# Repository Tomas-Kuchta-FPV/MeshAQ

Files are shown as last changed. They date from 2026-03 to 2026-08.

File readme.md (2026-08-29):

# MeshAQ
A portable sensor node designed to be carried and deployed anywhere.

This project serves as a development platform for Meshtastic, aiming to integrate the SEN6x family of environmental sensors and to support future upgrades in air quality and environmental telemetry within the Meshtastic ecosystem.

This project aimed to create the ultimate Air Quality sensor station to monitor. But after being a bit bussy I didn't have time to make it up to my original idea.  
But I managed to make a super small neat little all in one AQ helth monitor. Although I miss the other sensors.  
Formaldehyde sensor is super expensive and an increased levels can can be deducted from the VOC index.  

So yeah I'm so happy with the result! A neat little usb powered AQ station.

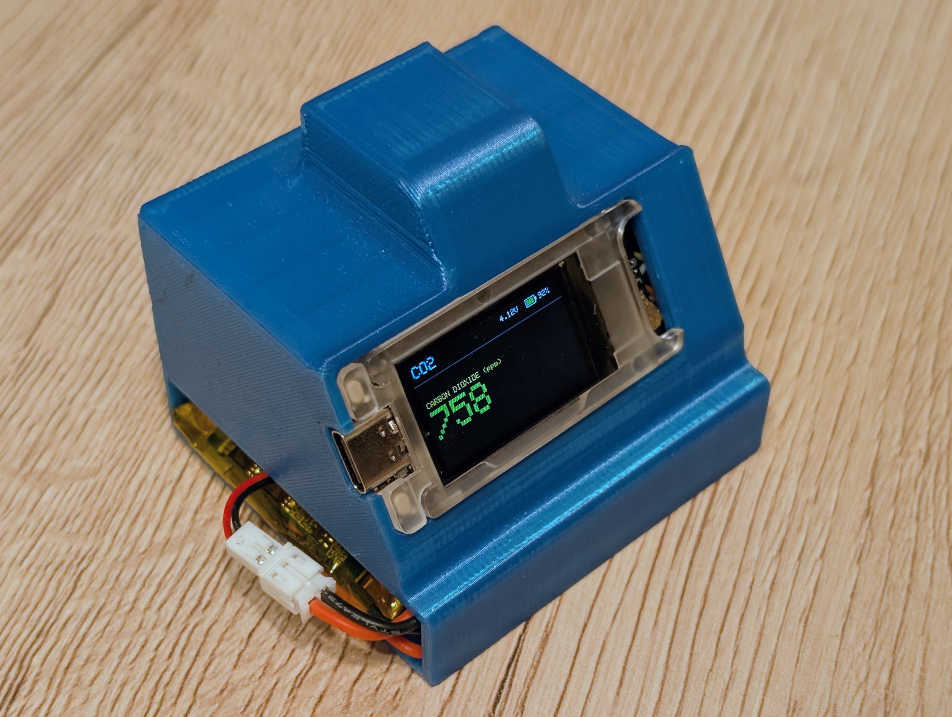
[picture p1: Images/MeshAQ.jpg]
Finished product


## Wiring diagram

| Heltec T114 Pin | SEN66 Pin | LaskaKit cable color |
| --- | --- | --- |
| GND | GND | Black |
| 3V3 | VCC | Red |
| GPIO 0.16 (SDA) | SDA | Blue |
| GPIO 0.13 (SCL) | SCL | Yellow |

## Sensors

| Measurement | Unit  | Sensor | Significance | Unhealthy level - suden spikes | Unhealthy level - 24h average |
| --- | ----- | --- | --- | --- | --- |
| Temperature | °C | SEN66  | Affects human comfort and thermoregulation; influences pollutant chemistry. | | >30°C (heat stress risk) |
| Relative humidity | % | SEN66  | Impacts respiratory comfort, aerosol growth, and mould/virus survival. | | <30% (dry) or >60% (mould/comfort issues) |
| PM (PM2.5) | µg/m³ | SEN66  | Fine particles penetrate lungs/bloodstream; linked to cardio-respiratory disease. | | annual ≤5 µg/m³; 24‑h >15 µg/m³ (exceedance) |
| PM (PM10) | µg/m³ | SEN66  | Alergens, dust and visible particles | |
| VOC Index | - | SEN66  | Sensor reports a relative VOC Index (unitless); indicates overall VOC load. | | Index >100 |
| NOx (NO2) | - | SEN66  | Sensor reports a relative NOx Index (unitless); NO2 is a respiratory irritant. | | Index >100 |
| CO2 | ppm | SEN66  | Proxy for ventilation and occupancy; high levels impair cognition. | | >1000 ppm (poor ventilation) |

### Future upgrades

| Measurement  | Unit  | Sensor | Significance | Unhealthy level - 24h average |
| --- | ----- | --- | --- | --- |
| Formaldehyde | ppm | SFA40 | Irritant and known carcinogen; common indoor emission from materials. | ?? |
| Ground Ozone | µg/m³ | (TBD) | Respiratory irritant and strong oxidant; forms from NOx/VOCs and sunlight. | Peak-season 8‑hr mean >60 µg/m³ |
| UV Index | - | LTR390UV / AMS AS7331 | Indicates UV radiation intensity; affects skin/eye health and photochemistry. | UVI >8 (very high/extreme exposure) |
| Sound level  | dB | TDK ICS43432 (mic) | High noise impacts sleep, stress, and hearing; affects wellbeing indirectly.  | >85 dB (prolonged exposure harmful) |

### Resources

- AI - It was crosschecked with material bellow
- https://www.who.int/publications/i/item/9789240034228
- https://sensirion.com/media/documents/02232963/6294E043/Info_Note_VOC_Index.pdf
- https://sensirion.com/media/documents/9F289B95/6294DFFC/Info_Note_NOx_Index.pdf
- https://sensirion.com/products/catalog/SEN66

## Renders

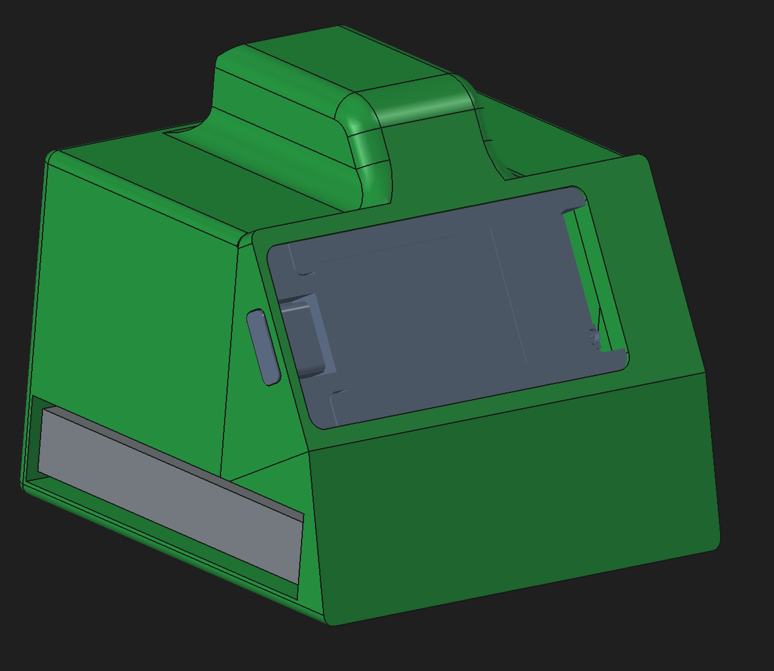
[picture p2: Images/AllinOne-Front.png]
Front
  
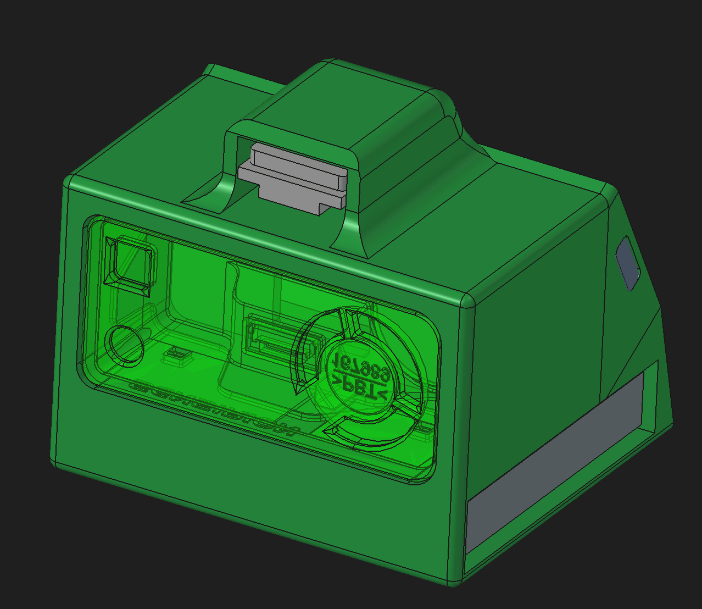
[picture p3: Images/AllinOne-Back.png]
Back
  
### Prototype
Prototype  

## Software

### Prototype for outpost
It will have it's own custom Arduino code made to interface with the sensor and display the values on the Eink screen.  

### Final version
I'm hoping to integrate it into meshtastic.  

## BOM

| Item | Price (USD) | Link & source |
| --- | --- | --- |
| 3d printed case | ~ 1 | MeshAQ.3mf |
| Heltec Mesh Node T114 | 63.38 | https://www.laskakit.cz/heltec-mesh-node-t114-v2-0-868mhz-nrf52840-sx1262/?variantId=17030 |
| SEN66 AQ sensor | 68.96 | https://www.laskakit.cz/senserion-sen66-sin-t-senzor-kvality-ovzdusi/ |
| JST GHR-06V-S connector | 0.85 | https://www.laskakit.cz/laskakit-airboard-propojovaci-kabel-pro-senserion-sen6x-senzor-kvality-ovzdusi/ |
| battery | 10.31 | https://www.laskakit.cz/baterie-li-po-3-7v-3000mah-lipo/ |
| JST-PH-2 2mm to JST 1.25mm | 0.85 | https://www.laskakit.cz/jst-ph-2-2mm-do-jst-gh-2-1-25mm-adapter-pro-baterie/ |
| Total | 144,35 |

## HackClub is fire! 🔥
https://blueprint.hackclub.com/projects/11552
https://github.com/Tomas-Kuchta-FPV/MeshAQ

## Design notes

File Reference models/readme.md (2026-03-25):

# Resources

SEN6x https://sensirion.com/products/catalog/SEN66  
heltec T114  
    https://www.printables.com/model/1610897-heltec-t114-simplified-3d-model/  
    https://www.printables.com/model/1003110-heltec-t114v1-model-file  
GPS L7GK
    https://www.printables.com/model/1604503-l76k-gnss-gps-board
case
    https://www.printables.com/model/797822-bender-battery-case-for-the-heltec-v3-heltec-t114

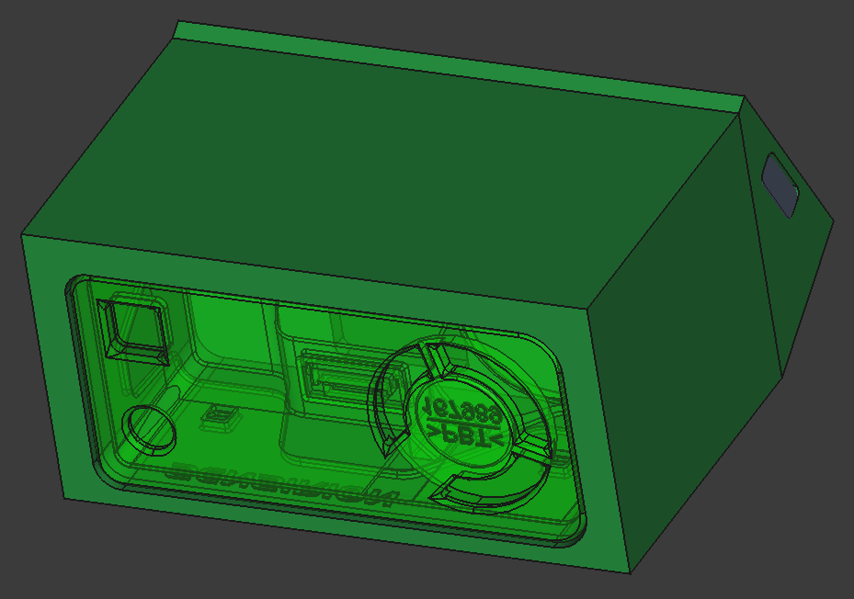
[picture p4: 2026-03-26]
Images/Back.png

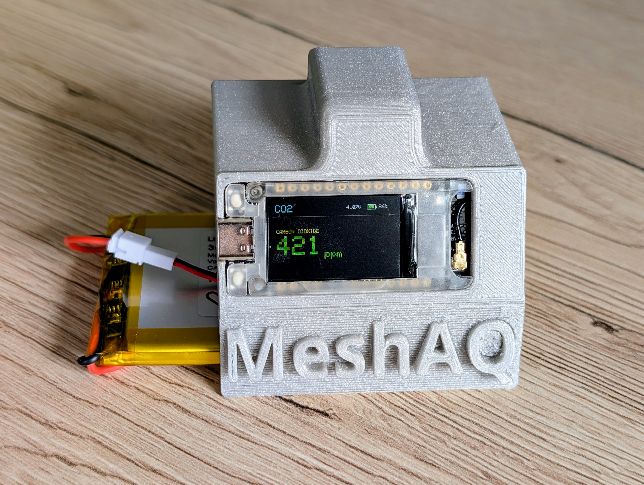
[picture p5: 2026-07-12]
Images/Finished product.jpg

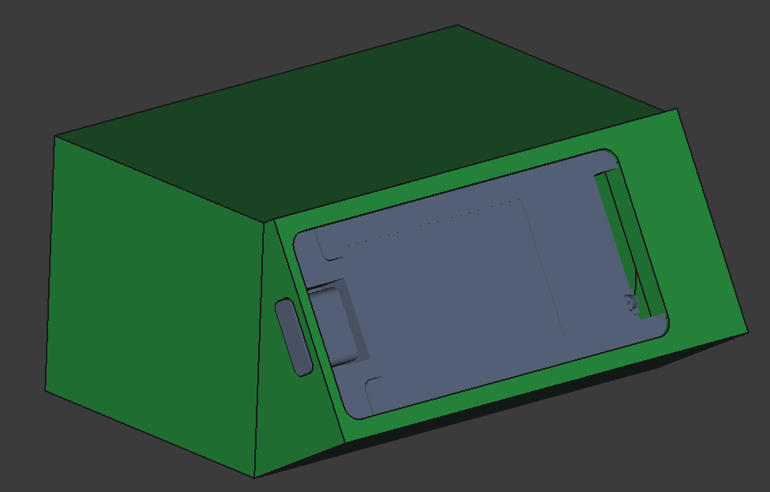
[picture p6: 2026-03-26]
Images/Front.png

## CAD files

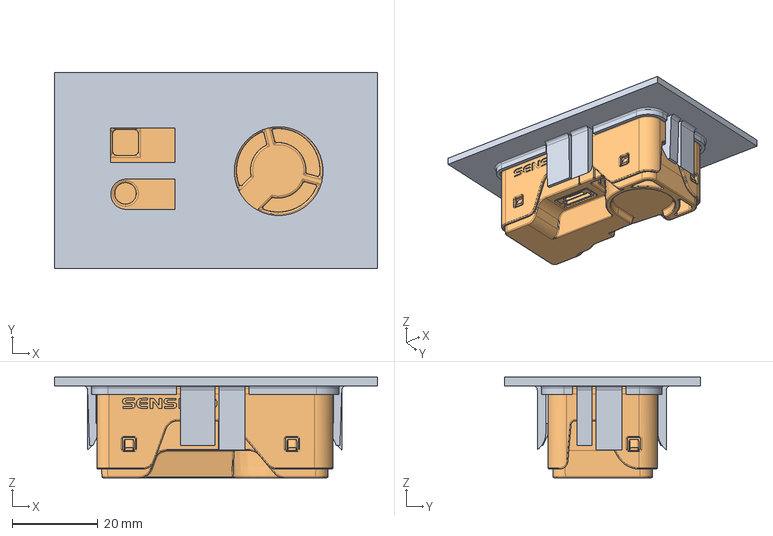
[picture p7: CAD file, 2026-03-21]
Reference models/SEN6x assembly.FCStd
75.5 x 45.9 x 23.5 mm
retainer_005
175875-00_Publication 3D File SEN6x

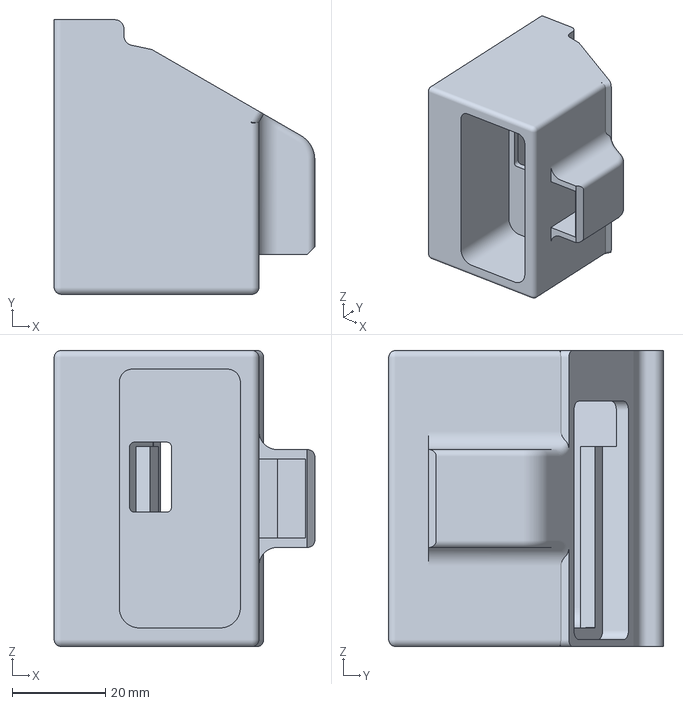
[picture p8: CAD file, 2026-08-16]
MeshAQ-3DPrintFile.3mf
56.0 x 59.0 x 63.6 mm

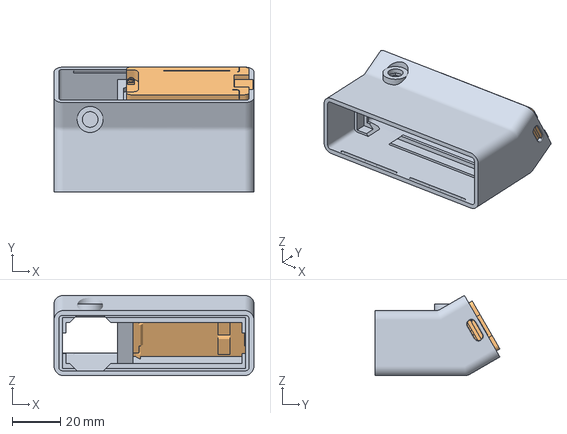
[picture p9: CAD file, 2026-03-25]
Reference models/bender.FCStd
83.0 x 51.8 x 33.3 mm
BenderBodyTopAntV1
HeltecT114 - Simplified dimensional drawing

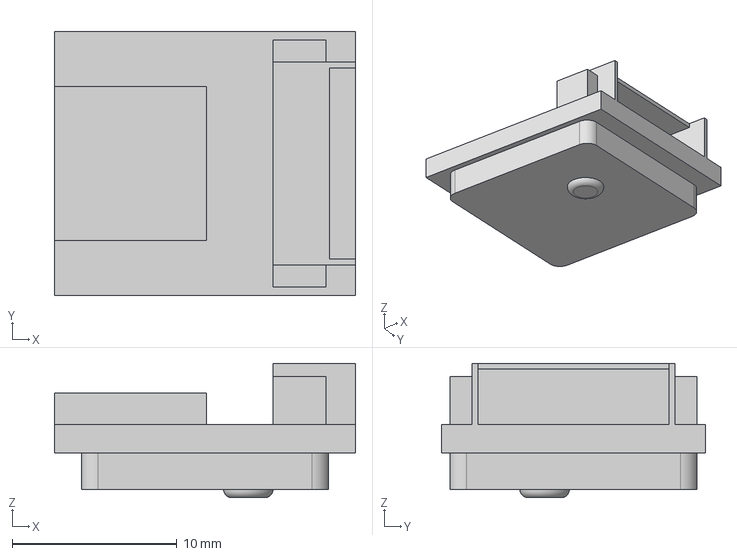
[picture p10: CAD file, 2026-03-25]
Reference models/l76k-gps-module.step
18.2 x 16.0 x 8.15 mm

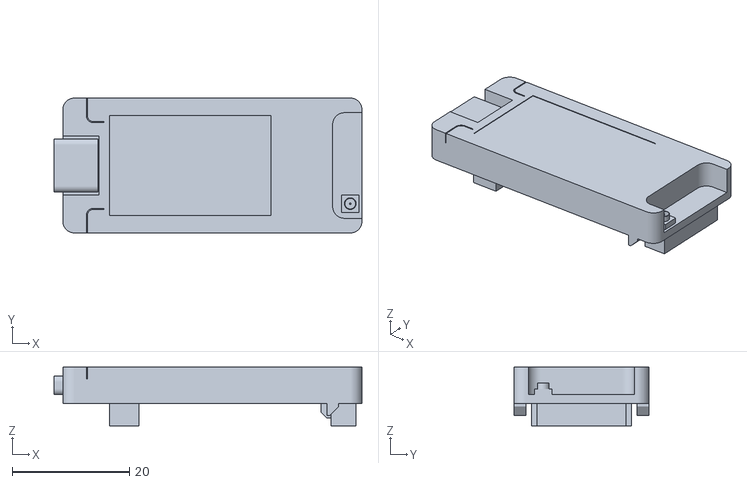
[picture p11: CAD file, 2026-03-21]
Reference models/HeltecT114 - Simplified dimensional drawing.stl
52.5 x 23.0 x 10.00

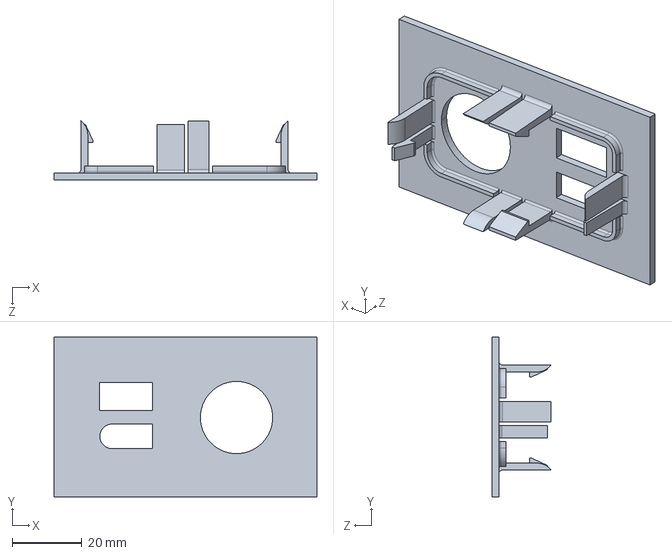
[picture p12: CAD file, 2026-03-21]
Reference models/SEN6x_Example_Retainer.step
75.5 x 45.9 x 17.0 mm

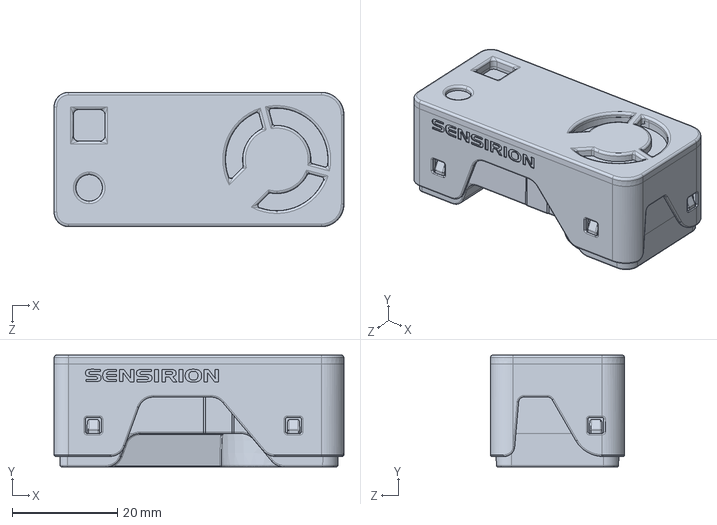
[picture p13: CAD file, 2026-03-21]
Reference models/PS_CD_SEN6x_D1.step
55.2 x 21.3 x 25.6 mm

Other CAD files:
MeshAQ-CAD.FCStd

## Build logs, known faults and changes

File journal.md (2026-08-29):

<!--
  Part of this journal is auto generated by Hack Club Blueprint.
-->

**Total Hours: 43.2h**
**Total Build Hours: 20.2h**

# 2/7/2026 1 PM - Research on enviromental monitoring  

_Time spent: 4.0h_  

I did a lot of research on enviromental monitoring.

I would like to measure metrics with which anyone can come into contact in everyday life.
I think that **temperature** and **relative humidity** are a baseline for comfort.
For office/home use I like **CO2**, **PM2.5**. These are all the basic ones which should suite almost everyone.

**Ground level ozone** seems like a great thing for an everyday node. 
**NO₂** and **Formaldehyde** are not super nessesary for everyday life but it's good to note traffic pollution and carcidogens. **VOCs** are good to measure but not strictly nesecery.
Then I started thinking about the **UV index** and **sound polution**, because smart citizen kits also measure these kinds of data. and it makes sense.

But I'm not a normal human.
I use paints, solvents, solder and other random stuff. So I also need **VOCs** and the other stuff. Also I would like to know how to mitigate the sources.

My references and sources are:
https://www.hackster.io/21cncstudio/project-aura-open-source-esp32-air-quality-monitor-8cb256
https://sensirion.com/products/catalog/particulate-matter-sensors
https://sensirion.com/products/catalog/SEN66
	There is already an arduino library for it.
	https://github.com/paulvha/SEN6X
	https://github.com/Sensirion/arduino-i2c-sen66
https://meshtastic.org/docs/configuration/module/telemetry/
https://smartcitizen.me/
	https://docs.smartcitizen.me/knowledge/
https://www.printables.com/model/1079858-3d-printer-emission-sensor-array-sensorbox-v2

I've made this table with chatgpt:

Metric | What it physically represents | What it’s good at telling you | Where it shines most | Best use case
-- | -- | -- | -- | --
PM1.0 | Particles <1 µm (ultrafine dust, combustion aerosols) | Deep lung–penetrating pollution, often from combustion | Indoor & outdoor | Traffic pollution, wildfire smoke, health-focused monitoring
PM2.5 | Fine particles <2.5 µm | The most health-relevant PM metric | Indoor & outdoor | Regulatory-style AQ monitoring, public health, smoke events
PM4.0 | Medium-fine particles | Transitional dust fraction (less standardized) | Indoor | HVAC efficiency, filtration studies
PM10 | Coarse particles <10 µm (dust, pollen, sand) | Mechanical dust and resuspended particles | Outdoor | Construction dust, agriculture, road dust
Temperature | Ambient air temperature | Context for sensor compensation and comfort | Indoor & outdoor | Thermal comfort, correcting PM/VOC readings
Relative Humidity (RH) | Water vapor content in air | Explains PM swelling and VOC sensor drift | Indoor & outdoor | Mold risk, PM correction, climate context
VOC index | Aggregate signal from volatile organic compounds | Human activity, off-gassing, indoor pollution trends | Indoor | Indoor air quality, occupancy/activity detection
NOx index | Nitrogen oxides (NO + NO₂ trend) | Combustion exhaust and traffic pollution | Outdoor & kitchens | Traffic exposure, gas stoves, combustion sources
CO₂ | Carbon dioxide concentration | Ventilation effectiveness and occupancy | Indoor | Ventilation control, classrooms, offices
Particle count | Number of particles by size | Source identification and dynamics | Indoor & outdoor | Research, aerosol behavior, diagnostics




# 2/7/2026 2 PM - Deciding on which sensors to use  

_Time spent: 2.5h_  

I'll firstly decide on the variables and with them decided I'll choose the sensors.

## Measurements:
- **Temperature and r. Humidity** these are no brainers.
- **CO2** is pretty important for my everyday life. In school I can't even open windows because of my classmates
- **VOC**, **HCHO** for when working in an enclosed spaces in winter. I sometimes paint or do some stupid stuff...
- **PMs** great for everyday life. And also for soldering, sanding and other workshop stuff. Oh yeah our electronics club sometimes gets super smoked out with solder fumes lol.
- I would also love to know **Ground level ozone** because it seems pretty important.

## Activities
assumptions of what will be affected by which activity

### Aikido
- Temperature will slightly increase
- humidity will rise
- CO2 will spike quite hard
- PM10 may see a spike as well

### Collage in winter
- Temperature will increase as our school saves on thermal energy and we are freezing there. 
- humidity will rise
- CO2 will spike quite hard, because my schoolmates doesn't want to open windows because it's cold
- I keep smelling a pretty funny smell when entering the class, so maybe HCHO or VOCs might spike.
- sound polution

### 3D printing
- Temperature will rise
- VOCs will be produced along with Formaldehyde
- and maybe PM will do something

### Electronics club
- Temperature will slightly increase
- humidity will rise
- CO2 will spike, we have open windows there.
- PM10 will rise because of soldering fumes, VOCs maybe too

## Sensor selection:
- As a base I chose **SEN66** with measurements of PM, RH/T, VOC, NOx and CO2
- **SFA30** for Formaldehyde
### These may be changed for other ones.
- There aren't a lot of options for Ozone sensors but this one looks promising. https://www.dfrobot.com/product-2005.html
- And maybe a **LTR390UV or AMS AS7331** and **TDK ICS43432** for UV and sound polution. I'm not really sold on these sensors yet.






# 2/15/2026 - SGP41  

_Time spent: 0.1h_  

So I've got my hand on SGP41 sensor and and thanks of the work of [ oscgonfer and Coloradohusky ](https://github.com/meshtastic/firmware/pull/4601) and it measures great! I'm really exited for this project and for revamping the enviroment metrics for the better.
This sensor is going to go into [Travel Buddy!](https://blueprint.hackclub.com/projects/8155)

https://github.com/meshtastic/firmware/pull/7198


# 3/21/2026 - Strated work on the CAD; Roughly decided on the design  

_Time spent: 4.0h_  



With the help of AI I was able to make a table over viewing the sensor which I planned to use. Like a month ago...
Now with 20 days until the blueprint deadline I have to scale back the scope.

That's why I've settled on using only the SEN66 with the heltec t114. I'm also super keen on adding a microphone nut I have a few at hand. But that will be for later.

After thinking of an elegant design I have came up with a slanted screen with the SEN on the back.

Did a few markups on paper and it looks promising. And it will look super smart!

Then I've jumped into CAD found the needed reference models for the SEN66 and the heltec t114. made an assembly for the sen and based my design of off it.

27aa8db5-c0e6-43f6-a0a8-b32edc9f332a~1





PS: I need to go to CT studios so adios  

# 3/24/2026 - Tried integrating the heltec T114  

_Time spent: 5.0h_  

Oh boy I'm struggling to come up with the right design today, even though I had the entire afternoon. Yeah nothing just works. A lot of the times I'm doing CAD the ideas just flow and I'm able to come up with a beautiful design. But not today. I's probably because I was attending a lot of competitions and events.

Yeah I'm not counting today as a super productive day. But every UP and DOWN should be documented so that's why I'm sharing my struggles. ;)

The journal isn't as juicy as there is with other days. So excuse me please. - Mainly images this time

I'm struggling with CADing up this design and I'm tight on time. The recepie for dezister.





I've managed to make it via a loft.


This doesn't seem right.


I don't know where to put the battery.


Even thought it looks decent there is no space for the intended 5Ah battery or for even a smaller one. Yeah so hopefully I'll be better tomorrow bye.

Even though I sat on it for like 7 hours I think it's appropriate to count 5.

Also I'm starting to doubt if this project is going to get accepted as I don't see it as fitting for blueprint. Going to ask in slack TMRW.



# 3/25/2026 - I still can't put the baterry in  

_Time spent: 2.0h_  

So Instead of basing the project around the SEN66 I based my design around the 5Ah battery I aleady have at hand. It looks ugly and the sensor is super small compared to the case.

So today with no luck either.

I'm pretty worried that this project wouldn't get accepted so I either put more of my unproductive time to it or I just settle for HackClub sponsoring just the sensor and I'll buy the heltec. Seems ethicaly right.



# 3/27/2026 - Finished it  

_Time spent: 3.0h_  

I've been mindful of the BOM in the beginning of the project. But I wasn't as mindful on the BOM price. And the Formaldehyde sensor was way too expensive.

So after reducing the BOM the project doesn't have the same complexity. But I think that it could still have the same informational functionality.

So I began striping things down. And in the end I only need one component and that is the SEN 66.

Then I went ahead and made a first draft of the BOM with links from farnel as they were the cheapest. (SPOILER: they were without VAT)

So I have imported the BOM into the readme. After I said a few words about the project and it's function.

Made a super simple schematic into the readme.

Screenshoted a few images of the CAD assembly exported.

And the I got to the farnel cart and noticed that the prices were without VAT so I went back to laskakit.

And there it was a complete project blueprint.

Front  
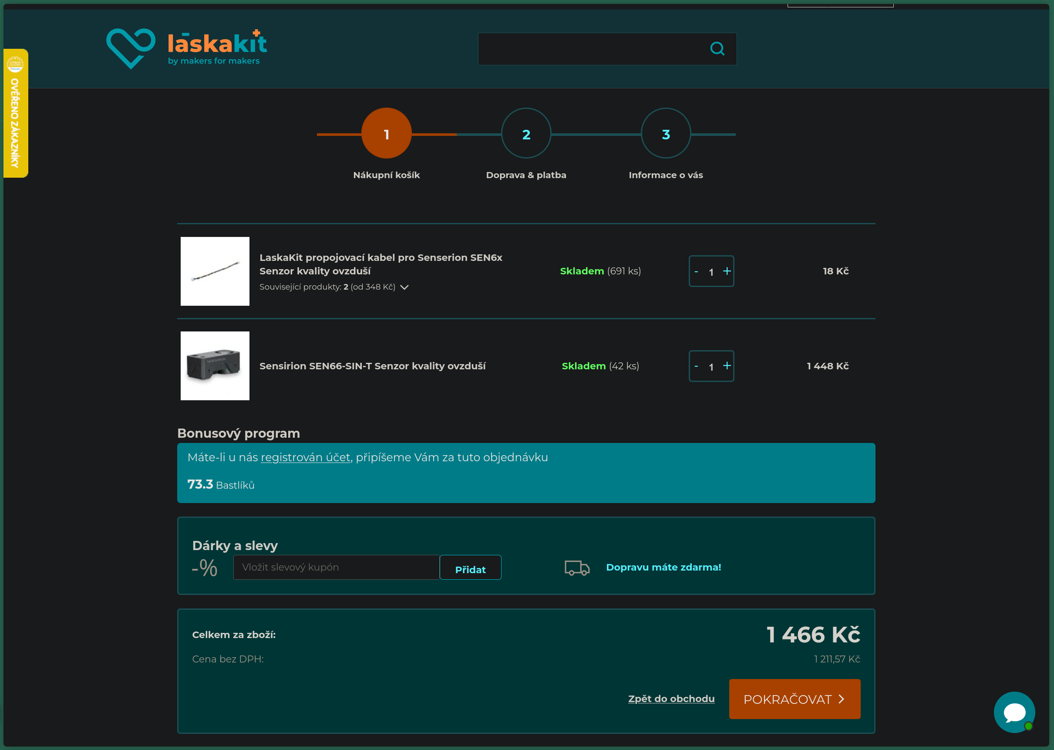
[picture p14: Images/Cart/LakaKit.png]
LakaKit
  

# 6/30/2026 - Finished it^2, and a small course correction - outpost migration

_Time spent: 3.0h_  

I have never gotten a grant to build this one lol.  
So why not revive this at outpost and show it at open sauce!  
I think that the idea is really cool. I have one meshtastic on hand (Heltec E290) which is kinda suitable. ESP32S3 for low power grrr.  
Yeah so I have this week to finish it. That's why I had ordered the SEN66 out off pocket and hoping for a reimbursment later. Also If I get the grant I'll swith to the heltec t114 which is way better for low power stuff and also I've already made and printed a minimalistic case for it. Also the prices on aliexpress got redicolous and buying locally makes more sense lol.  

CaseV1  

And yah I have also designed a new case for it with a place for a battery and I didn't bother CADing the place for the heltec. Also I want this portable so that's why I need a battery.  

CaseV2.1  
CaseV2.2  

So I would love to revisit it with the HW I have at hand. not BC I have a week to build it.  
Also it's going to get simplified like a lot.  
### Parts:
- Heltec vision master E290
- SEN66
### SW:
Even though this was and still is meant for meshtastic I'm going to code my own software as there is no way I could integrate SEN66 that fast.  

Next I'll do the SW,CAD and ship it! :yay

# 7/1/2026 - Finished it^2, code for the prototype

_Time spent: 3.5h_  
So today I had began to code some code for it. I don't have the sensor yet but the post said it should get here by tomorrow.  
My goal for today was to define what the code should do and display all the variables that will be produced by the sensor.  
I have first tried the example givven by heletec but I didn't like the fact it's a generic nonmodular library so I went with a comunnity one which worked nice.  
So BC IDK how to make a pretty colums for the measurements I let AI to make a function that will handle the colums.  
And after that I had my first prototype ready. Which only incremented n by one evehy cycle but it was enough to validate the UI.  
Finished UI  

# Build

# 7/2/2026 - Finished the prototype

_Time spent: 4.0h_  

I woke up to a door slamming and I really didn't have a clue what it was. But it turned out to be GLS with my order!  
So with my brother we imedeatly opened it up and was really exited that the sensor came in.  
After breakfest I imeadedly went to my worksop and connected the sensor, also I have triple checked everything BC this sensor can't get fried.  
So after hooking it up I've uploaded the test code from SEN6x library and it worked first try!  
And after that succes I've coded I've imedeatly started coding code for it. I mean I just copied code blocks from the example and hooked everything to the coresponding values. And at first the aligment was wonky but with some tweaks later it looks pretty good.  

First prototype done

# 7/2/2026 - Made an all in one case

_Time spent: 2.0h_  

Last time I did a minimalistic case for it, but now I wanted to have everything contained. So I designed a super goofy case for it! YAY But it houses everything ig.  
I'm not that proud but should get the job done. it looks like a freaking frog.  
Also FreeCAD anoys me bc it doesn't support text. But Prusaslices came for a rescue. 	

CAse  
CAse  
PrusaSlicer  

# 7/11/2026 - Integration to the case and a bit of code

_Time spent: 6.7h_

  
  

Allright so after an amazing family vacation...  



I've got home and I found the package from lakakit home thanks to my dad bc he grabbed from the post office. Also I have printed the case before the vacation and cleaned up the suports.   
I was super happy about building it!!!! Like let's goooo and let's build it.  
  
So I've started working on it ASAP, bc I'm super exited about it.  
Started with a rough assembly to find problems and there were a lot of problems lol bc I was rushing it.  

**Problems found:**
- Hole for the GPS it soo tall
- Hole for the GPS cable is too small
- GPS cable toooooo short
- Didn't tolerance the SEN66 sensor in any shape or form.
- Battery is too long wth
- Looks like a frog
- No place for the antenna - TSA might look at me wrong fah
- No passthrough for battery cable

Oh man IDK I'm rushing it madmax style.  
So I've made the cable longer (Which was a pain in the hack) managed to get it passed through by scraping a bit off the connector. FAHHHH  
  
  
  

Oh and then there was ZEN as the SEN66 assebly was a lot more smooooother.  
It fitted so smoothly and It worked almost first try niiiiceee.  
So I have tried the example sketch on it but it didn't work as I2C pins aren't prob defined in arduino same as in meshtastic.  So with a bit of help from AI I've managed to insert one line to define the pins and it worked out good.  

  
  

# 7/12/2026 - Made an all in one case

_Time spent: 4h_

Allrighty so after yeasterday succes I had today tried codind some code for it. Like I have a lot of thing to prepare for the hackathon so I'm going to vibecode it with claude. And yeah it worked wonderfully. The UI is clean and it works.  
I had one hurdle with ADC as AI thought it was the correct code for t114 but it was for the e290.  
I have also tried to add in GPS support but I ran out of contex and tokens.  

Looks super neat, and I can't wait to measure the nasty air at the venue lol.  
  
[Video of it working](https://cdn.hackclub.com/019f56bc-70db-7756-8306-433a7e309648/1000039035.mp4)  
Moved to
https://stardance.hackclub.com/projects/49514

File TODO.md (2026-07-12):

- [ ] Add hole for the battery
- [ ] Think more abt antenna placement
- [ ] Tolerance the place for the T114
- [ ] Add a longer GPS cable to BOM
- [ ] Make hole bigger for the GPS cable

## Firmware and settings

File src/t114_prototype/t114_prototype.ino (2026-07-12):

/**
 * SEN66 air quality sensor + GPS readout on Heltec Mesh Node T114
 *
 * Reads temperature, humidity, PM1.0/2.5/4.0/10.0, VOC index, NOX index and
 * CO2 from a Sensirion SEN66, plus position from the onboard L76K GNSS
 * module, and shows them on the onboard 1.14" ST7789 TFT.
 *
 * Five screens, rotated either by a short press of the USER button or
 * automatically every 30 seconds:
 *   1) Temperature + Humidity
 *   2) Particulate matter (PM1.0 / PM2.5 / PM4.0 / PM10.0)
 *   3) VOC index + NOX index
 *   4) CO2
 *   5) GPS (fix status / satellites / lat / lon / altitude) - no workie for now
 *
 * Holding the USER button for ~1.5s toggles the GPS module on/off to save
 * power when you don't need position data.
 *
 * Battery percentage is shown in the top-right corner of every screen.
 *
 * Board:   Heltec Mesh Node T114  https://docs.heltec.org/en/node/nrf/mesh_node_t114/quick_start.html
 * Sensor:  Sensirion SEN66        (I2C)
 * GNSS:    Quectel L76K           (UART, Serial1)
 * Display: 1.14" ST7789 135x240   (SPI1)
 *
 * Libraries required (Library Manager):
 *   - Sensirion I2C SEN66 (SensirionI2cSen66)
 *   - Adafruit GFX Library
 *   - Adafruit ST7735 and ST7789 Library
 *   - TinyGPSPlus (by Mikal Hart)
 */

#include <Adafruit_GFX.h>
#include <Adafruit_ST7789.h>
#include <Arduino.h>
#include <TinyGPSPlus.h>
#include <Wire.h>
#include "SensirionI2cSen66.h"

#ifdef NO_ERROR
#undef NO_ERROR
#endif
#define NO_ERROR 0

// ------------------------------------------------------------------------
// Pin definitions
// ------------------------------------------------------------------------

// -- Battery ADC --
// These come from the actual T114 board variant.h (meshtastic/firmware),
// not the SEN66 sample - that sample's battery-read pins/coefficient
// were for a different board (Heltec E290) and don't apply here.
#define BATTERY_ADC_CTRL_PIN 6      // must be driven HIGH to enable the divider
#define BATTERY_ADC_CTRL_ENABLED HIGH
#define BATTERY_PIN 4               // AIN2 on the nRF52840
#define BATTERY_SENSE_RESOLUTION_BITS 12
#define BATTERY_SENSE_RESOLUTION 4096.0f
#define BATTERY_AREF_VOLTAGE 3.0f   // internal 3.0V ADC reference, not VDD
#define BATTERY_ADC_MULTIPLIER 4.916f // includes the onboard divider ratio

// -- SEN66 I2C --
#define SEN66_SDA_PIN 16
#define SEN66_SCL_PIN 13

// -- GPS (L76K) --
// Values taken from the T114 board variant.h used by Meshtastic firmware
// (a different build than this Arduino sketch, so defined fresh here
// rather than assumed to already exist in this board package).
#define GPS_STANDBY_PIN (32 + 2) // output: LOW = allow GPS to sleep, HIGH = force wake
#define GPS_RX_PIN       (32 + 5) // our RX <- GPS TX
#define GPS_TX_PIN       (32 + 7) // our TX -> GPS RX
#define GPS_BAUD         9600

// -- TFT (from Heltec T114 variant) --
#define SOC_GPIO_PIN_T114_VEXT_EN    21  // P0.21
#define TFT_WIDTH  135
#define TFT_HEIGHT 240
#define SOC_GPIO_PIN_T114_TFT_MOSI   9   // P1.09
#define SOC_GPIO_PIN_T114_TFT_MISO   11  // P1.11 NC
#define SOC_GPIO_PIN_T114_TFT_SCK    8   // P1.08
#define SOC_GPIO_PIN_T114_TFT_SS     11  // P0.11
#define SOC_GPIO_PIN_T114_TFT_DC     12  // P0.12
#define SOC_GPIO_PIN_T114_TFT_RST    2   // P0.02
#define SOC_GPIO_PIN_T114_TFT_EN     3   // P0.03
#define SOC_GPIO_PIN_T114_TFT_BLGT   15  // P0.15

// -- USER button --
// NOTE: this is the button that ships with the T114 and is used by
// Meshtastic firmware to cycle screens. Double check this pin number
// against your board revision (see the T114 pinout diagram / variant.h)
// before relying on it - if button presses don't register, this is the
// first thing to change. Wired active-LOW with an internal pull-up.
#define BUTTON_PIN (32 + 10)

// ------------------------------------------------------------------------
// Timing configuration
// ------------------------------------------------------------------------
#define SENSOR_POLL_INTERVAL_MS   1000    // how often we ask the SEN66 if data is ready
#define SCREEN_AUTO_ROTATE_MS     30000   // auto-advance screen after this long
#define BUTTON_DEBOUNCE_MS        200

// ------------------------------------------------------------------------
// Globals
// ------------------------------------------------------------------------

static char errorMessage[64];
static int16_t error;

SensirionI2cSen66 sensor;
Adafruit_ST7789 tft(&SPI1, SOC_GPIO_PIN_T114_TFT_SS, SOC_GPIO_PIN_T114_TFT_DC, SOC_GPIO_PIN_T114_TFT_RST);
TinyGPSPlus gps;

uint8_t padding = 0;
bool dataReady = false;
bool haveValidReading = false; // becomes true after first successful read

float massConcentrationPm1p0 = 0.0;
float massConcentrationPm2p5 = 0.0;
float massConcentrationPm4p0 = 0.0;
float massConcentrationPm10p0 = 0.0;
float humidity = 0.0;
float temperature = 0.0;
float vocIndex = 0.0;
float noxIndex = 0.0;
uint16_t co2 = 0;

float battVoltage = 0.0;
uint8_t battPercent = 0;

bool gpsEnabled = false; // set true in setup() once GPS is brought up

// GPS link verification - lets the GPS screen distinguish "module not
// talking to us at all" (wiring/baud problem) from "talking fine, just
// no satellite fix yet" (normal, can take a while outdoors/never indoors)
unsigned long gpsEnabledAtMs = 0;
bool gpsAnyByteSinceEnable = false;
uint32_t gpsChecksumBaselineAtEnable = 0;
#define GPS_WARMUP_MS      2000 // grace period right after enabling before judging the link
#define GPS_NOISE_GRACE_MS 3000 // how long to wait for at least one *valid* sentence

enum GpsLinkState : uint8_t {
  GPS_LINK_OFF = 0,
  GPS_LINK_WARMING_UP,
  GPS_LINK_NO_DATA,   // enabled, but nothing at all coming in on the UART
  GPS_LINK_NOISE,     // bytes coming in, but none parse as valid NMEA
  GPS_LINK_SEARCHING, // valid NMEA sentences, no fix yet
  GPS_LINK_FIX
};

enum Screen : uint8_t {
  SCREEN_TEMP_HUMIDITY = 0,
  SCREEN_PM,
  SCREEN_VOC_NOX,
  SCREEN_CO2,
  SCREEN_GPS,
  SCREEN_COUNT
};

uint8_t currentScreen = SCREEN_TEMP_HUMIDITY;
bool screenSwitchPending = true;   // true right after changing screens -> full redraw (title/labels/etc)
bool contentUpdatePending = false; // true when data changed but screen didn't -> values only, no flicker

unsigned long lastSensorPollMs = 0;
unsigned long lastScreenChangeMs = 0;

// Button state, updated from the interrupt + polled in loop() to tell a
// short press (change screen) from a long press/hold (toggle GPS)
volatile bool buttonEdgeFlag = false;
volatile unsigned long lastInterruptMs = 0;
bool buttonIsDown = false;
unsigned long buttonDownStartMs = 0;
bool longPressHandled = false;
#define LONG_PRESS_MS 1500

// ------------------------------------------------------------------------
// Button handling
// ------------------------------------------------------------------------

// nRF52 doesn't require/have IRAM_ATTR (that's an ESP32-ism), so the ISR
// is declared plain here. This only records that a press started - the
// short-vs-long-press decision happens in loop() by polling the pin.
void buttonISR() {
  unsigned long now = millis();
  if (now - lastInterruptMs > BUTTON_DEBOUNCE_MS) {
    buttonEdgeFlag = true;
    lastInterruptMs = now;
  }
}

// ------------------------------------------------------------------------
// Battery helpers
// ------------------------------------------------------------------------

float readBatteryVoltage() {
  int raw = analogRead(BATTERY_PIN);
  return (raw / BATTERY_SENSE_RESOLUTION) * BATTERY_AREF_VOLTAGE * BATTERY_ADC_MULTIPLIER;
}

// Rough single-cell LiPo discharge curve -> percentage
uint8_t voltageToPercent(float v) {
  static const float voltPoints[] = {3.30, 3.50, 3.60, 3.70, 3.75, 3.80, 3.85, 3.90, 3.95, 4.00, 4.10, 4.20};
  static const uint8_t pctPoints[] = {0,    5,    10,   20,   30,   40,   50,   60,   70,   80,   90,   100};
  const int n = sizeof(voltPoints) / sizeof(voltPoints[0]);

  if (v <= voltPoints[0]) return pctPoints[0];
  if (v >= voltPoints[n - 1]) return pctPoints[n - 1];

  for (int i = 0; i < n - 1; i++) {
    if (v >= voltPoints[i] && v <= voltPoints[i + 1]) {
      float frac = (v - voltPoints[i]) / (voltPoints[i + 1] - voltPoints[i]);
      return (uint8_t)(pctPoints[i] + frac * (pctPoints[i + 1] - pctPoints[i]));
    }
  }
  return 0;
}

// ------------------------------------------------------------------------
// GPS control
// ------------------------------------------------------------------------

void setGpsEnabled(bool enable) {
  gpsEnabled = enable;
  digitalWrite(GPS_STANDBY_PIN, enable ? HIGH : LOW);

  if (enable) {
    Serial1.begin(GPS_BAUD);
    gpsEnabledAtMs = millis();
    gpsAnyByteSinceEnable = false;
    gpsChecksumBaselineAtEnable = gps.passedChecksum();
  } else {
    Serial1.end();
  }

  Serial.print("GPS ");
  Serial.println(enable ? "enabled" : "disabled");

  if (currentScreen == SCREEN_GPS) {
    contentUpdatePending = true;
  }
}

void toggleGps() {
  setGpsEnabled(!gpsEnabled);
}

// Distinguishes "module not talking to us at all" from "talking fine,
// just no fix yet" - see the enum above for what each state means.
GpsLinkState getGpsLinkState() {
  if (!gpsEnabled) return GPS_LINK_OFF;

  unsigned long sinceEnable = millis() - gpsEnabledAtMs;
  uint32_t sentencesSinceEnable = gps.passedChecksum() - gpsChecksumBaselineAtEnable;

  if (sinceEnable < GPS_WARMUP_MS) {
    return GPS_LINK_WARMING_UP;
  }
  if (sentencesSinceEnable > 0) {
    return gps.location.isValid() ? GPS_LINK_FIX : GPS_LINK_SEARCHING;
  }
  if (sinceEnable < GPS_NOISE_GRACE_MS) {
    return GPS_LINK_WARMING_UP; // not enough time yet to judge fairly
  }
  return gpsAnyByteSinceEnable ? GPS_LINK_NOISE : GPS_LINK_NO_DATA;
}

// ------------------------------------------------------------------------
// Sensor reading
// ------------------------------------------------------------------------

void pollSensor() {
  error = sensor.getDataReady(padding, dataReady);
  if (error != NO_ERROR) {
    dataReady = false;
    return;
  }

  if (dataReady) {
    error = sensor.readMeasuredValues(
      massConcentrationPm1p0, massConcentrationPm2p5, massConcentrationPm4p0,
      massConcentrationPm10p0, humidity, temperature, vocIndex, noxIndex, co2);
    if (error != NO_ERROR) {
      dataReady = false;
      return;
    }
    haveValidReading = true;
    contentUpdatePending = true; // fresh data -> refresh values in place, no full clear
  }

  battVoltage = readBatteryVoltage();
  battPercent = voltageToPercent(battVoltage);
  updateBatteryIndicator(); // cheap + localized, keep it live every poll regardless of screen
}

// ------------------------------------------------------------------------
// Drawing helpers
// ------------------------------------------------------------------------

#define COLOR_BG      ST77XX_BLACK
#define COLOR_TITLE   ST77XX_CYAN
#define COLOR_TEXT    ST77XX_WHITE
#define COLOR_LABEL   ST77XX_YELLOW
#define COLOR_GOOD    ST77XX_GREEN
#define COLOR_WARN    ST77XX_YELLOW
#define COLOR_BAD     ST77XX_RED
#define COLOR_GRAY    0x7BEF  // RGB565 medium grey - not defined by the Adafruit lib itself

void drawBattery(int x, int y) {
  // Small battery glyph: outline + nub + fill proportional to charge
  const int w = 16, h = 10, nub = 2;

  uint16_t fillColor = COLOR_GOOD;
  if (battPercent < 20) fillColor = COLOR_BAD;
  else if (battPercent < 50) fillColor = COLOR_WARN;

  tft.setTextSize(1);
  tft.setTextColor(COLOR_TEXT, COLOR_BG);
  tft.setCursor(x, y + 1);
  tft.print(battVoltage, 2);
  tft.print("V");

  int battX = x + 42; // leave room for the "X.XXV" text before the icon

  tft.drawRect(battX, y, w, h, COLOR_TEXT);
  tft.fillRect(battX + w, y + h / 2 - 2, nub, 4, COLOR_TEXT);

  int innerW = w - 4;
  int fillW = (innerW * battPercent) / 100;
  tft.fillRect(battX + 2, y + 2, innerW, h - 4, COLOR_BG); // clear old fill
  if (fillW > 0) {
    tft.fillRect(battX + 2, y + 2, fillW, h - 4, fillColor);
  }

  tft.setTextColor(COLOR_TEXT, COLOR_BG);
  tft.setCursor(battX + w + nub + 4, y + 1);
  tft.print(battPercent);
  tft.print("%");
}

void drawHeader(const char* title) {
  tft.setTextSize(2);
  tft.setTextColor(COLOR_TITLE, COLOR_BG);
  tft.setCursor(4, 4);
  tft.print(title);

  drawBattery(tft.width() - 96, 6);

  tft.drawFastHLine(0, 26, tft.width(), COLOR_GRAY);
}

// Battery glyph position, fixed across every screen (header sits at the
// same coordinates everywhere), so this can be called any time to keep
// it live without touching the rest of the screen.
void updateBatteryIndicator() {
  drawBattery(tft.width() - 96, 6);
}

// Everything below the header divider - used to refresh a screen's whole
// content region without wiping the header/battery (still much cheaper
// than a full fillScreen, and used for screens too irregular to easily
// patch field-by-field, e.g. the multi-state GPS screen).
#define CONTENT_TOP 28
void clearContent() {
  tft.fillRect(0, CONTENT_TOP, tft.width(), tft.height() - CONTENT_TOP, COLOR_BG);
}

// Redraws a single numeric field inside a fixed-size box, clearing only
// that box first. This is what actually kills the flicker: each value
// gets its own small rect cleared instead of the whole screen.
void drawValueInBox(int x, int y, int w, int h, uint8_t textSize, const String& text, uint16_t color) {
  tft.fillRect(x, y, w, h, COLOR_BG);
  tft.setTextSize(textSize);
  tft.setTextColor(color, COLOR_BG);
  tft.setCursor(x, y);
  tft.print(text);
}

uint16_t co2Color(uint16_t ppm) {
  if (ppm < 800) return COLOR_GOOD;
  if (ppm < 1200) return COLOR_WARN;
  return COLOR_BAD;
}

uint16_t indexColor(float idx) {
  // SEN6x VOC/NOX index: ~100 is average/baseline, higher = worse
  if (idx < 150) return COLOR_GOOD;
  if (idx < 250) return COLOR_WARN;
  return COLOR_BAD;
}

// ------------------------------------------------------------------------
// Screens
// ------------------------------------------------------------------------
// Each screen has two functions:
//  - drawStaticX():   fillScreen + header + labels/units. Only called when
//                      switching TO this screen - this is the "expensive"
//                      full-clear draw.
//  - updateXValues():  redraws just the numbers, each in its own small box
//                      (fillRect sized to the field, not the screen), so
//                      routine data refreshes don't blank/flash anything.

// -- Temp / Humidity --

void drawStaticTempHumidity() {
  tft.fillScreen(COLOR_BG);
  drawHeader("Temp / RH");

  tft.setTextSize(1);
  tft.setTextColor(COLOR_LABEL, COLOR_BG);
  tft.setCursor(6, 38);
  tft.print("TEMPERATURE (C)");
  tft.setCursor(6, 78);
  tft.print("HUMIDITY (%RH)");
}

void updateTempHumidityValues() {
  String tempStr = haveValidReading ? String(temperature, 1) : "--";
  String humStr  = haveValidReading ? String(humidity, 1) : "--";
  drawValueInBox(6, 48, 110, 26, 3, tempStr, COLOR_TEXT);
  drawValueInBox(6, 88, 110, 26, 3, humStr, COLOR_TEXT);
}

// -- PM --

void drawStaticPM() {
  tft.fillScreen(COLOR_BG);
  drawHeader("PM (ug/m3)");

  tft.setTextSize(1);
  tft.setTextColor(COLOR_LABEL, COLOR_BG);
  const char* labels[4] = {"PM1.0", "PM2.5", "PM4.0", "PM10"};
  int y = 36;
  for (int i = 0; i < 4; i++) {
    tft.setCursor(6, y);
    tft.print(labels[i]);
    y += 24;
  }
}

void updatePMValues() {
  float values[4] = {massConcentrationPm1p0, massConcentrationPm2p5,
                      massConcentrationPm4p0, massConcentrationPm10p0};
  int y = 34; // matches label rows, box sits slightly above label baseline
  for (int i = 0; i < 4; i++) {
    String v = haveValidReading ? String(values[i], 1) : "--";
    drawValueInBox(70, y, 70, 18, 2, v, COLOR_TEXT);
    y += 24;
  }
}

// -- VOC / NOX --

void drawStaticVocNox() {
  tft.fillScreen(COLOR_BG);
  drawHeader("VOC / NOX");

  tft.setTextSize(1);
  tft.setTextColor(COLOR_LABEL, COLOR_BG);
  tft.setCursor(6, 38);
  tft.print("VOC INDEX");
  tft.setCursor(6, 78);
  tft.print("NOX INDEX");
}

void updateVocNoxValues() {
  String vocStr = haveValidReading ? String(vocIndex, 0) : "--";
  String noxStr = haveValidReading ? String(noxIndex, 0) : "--";
  uint16_t vocColor = haveValidReading ? indexColor(vocIndex) : COLOR_TEXT;
  uint16_t noxColor = haveValidReading ? indexColor(noxIndex) : COLOR_TEXT;
  drawValueInBox(6, 48, 90, 26, 3, vocStr, vocColor);
  drawValueInBox(6, 88, 90, 26, 3, noxStr, noxColor);
}

// -- CO2 --

void drawStaticCO2() {
  tft.fillScreen(COLOR_BG);
  drawHeader("CO2");

  tft.setTextSize(1);
  tft.setTextColor(COLOR_LABEL, COLOR_BG);
  tft.setCursor(6, 50);
  tft.print("CARBON DIOXIDE (ppm)");
}

void updateCO2Values() {
  String co2Str = haveValidReading ? String(co2) : "--";
  uint16_t color = haveValidReading ? co2Color(co2) : COLOR_TEXT;
  drawValueInBox(6, 62, 150, 40, 5, co2Str, color);
}

// -- GPS --
// Too many distinct layouts (off / warming up / no data / noise /
// searching / fix, each with different text) to cleanly box-diff field
// by field, so this one just clears its content area (not the whole
// screen) and redraws - still avoids flickering the header/battery.

void drawStaticGPS() {
  tft.fillScreen(COLOR_BG);
  drawHeader("GPS");
}
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
void loop() {
  unsigned long now = millis();

  // Poll the sensor periodically (non-blocking)
  if (now - lastSensorPollMs >= SENSOR_POLL_INTERVAL_MS) {
    lastSensorPollMs = now;
    pollSensor();

    if (dataReady) {
      Serial.print("T:"); Serial.print(temperature);
      Serial.print(" RH:"); Serial.print(humidity);
      Serial.print(" PM1:"); Serial.print(massConcentrationPm1p0);
      //Serial.print(" PM2.5:"); Serial.print(massConcentrationPm2p5);
      Serial.print(" PM4:"); Serial.print(massConcentrationPm4p0);
      Serial.print(" PM10:"); Serial.print(massConcentrationPm10p0);
      Serial.print(" VOC:"); Serial.print(vocIndex);
      Serial.print(" NOX:"); Serial.print(noxIndex);
      Serial.print(" CO2:"); Serial.print(co2);
      Serial.print(" Batt:"); Serial.print(battPercent);
      Serial.println("%");
    }

    // Keep the GPS screen refreshing (sat count / fix status) even
    // between NMEA updates, e.g. while still searching for a fix.
    if (currentScreen == SCREEN_GPS) {
      contentUpdatePending = true;
    }
  }

  // Feed any waiting NMEA bytes to the GPS parser
  if (gpsEnabled) {
    while (Serial1.available()) {
      gpsAnyByteSinceEnable = true;
      gps.encode(Serial1.read());
    }
    if (currentScreen == SCREEN_GPS &&
        (gps.location.isUpdated() || gps.satellites.isUpdated() || gps.hdop.isUpdated())) {
      contentUpdatePending = true;
    }
  }

  // -- Button: short press = next screen, long press (~1.5s) = toggle GPS --
  if (buttonEdgeFlag) {
    buttonEdgeFlag = false;
    if (!buttonIsDown) {
      buttonIsDown = true;
      buttonDownStartMs = now;
      longPressHandled = false;
    }
  }

  if (buttonIsDown) {
    bool stillHeld = (digitalRead(BUTTON_PIN) == LOW); // active-low button
    unsigned long heldFor = now - buttonDownStartMs;

    if (!longPressHandled && heldFor >= LONG_PRESS_MS) {
      toggleGps();
      longPressHandled = true;
    }

    if (!stillHeld) {
      // Released - only treat as a screen-change if it wasn't already
      // handled as a long press
      if (!longPressHandled) {
        nextScreen();
      }
      buttonIsDown = false;
    }
  }

  // Automatic rotation after timeout
  if (now - lastScreenChangeMs >= SCREEN_AUTO_ROTATE_MS) {
    nextScreen();
  }

  // Full redraw only when the screen actually changed; otherwise just
  // patch the values in place - this is what removes the flicker.
  if (screenSwitchPending) {
    drawScreenStatic(currentScreen);
    updateScreenContent(currentScreen); // fill in values immediately, don't wait for next poll
    screenSwitchPending = false;
    contentUpdatePending = false;
  } else if (contentUpdatePending) {
    updateScreenContent(currentScreen);
    contentUpdatePending = false;
  }
}

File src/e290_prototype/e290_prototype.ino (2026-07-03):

// Ideal endpoint
/*
Read data from SEN66 once per 1m
Display them, and lastly make pretty graphs(Optional).
*/
// Board: Heltech Vision Madter E290 => https://github.com/todd-herbert/heltec-eink-modules/blob/main/docs/VisionMaster/vision_master.md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

#include "heltec-eink-modules.h"
#include "SensirionI2cSen66.h"

#include "Wire.h"
#include "esp_sleep.h"


#ifdef NO_ERROR
#undef NO_ERROR
#endif
#define NO_ERROR 0

#define VBAT_PIN 7
#define Resolution 0.000244140625 
#define battery_in 3.3
#define coefficient 1.199

static char errorMessage[64];
static int16_t error;

// Fonts
#include "Fonts/FreeSans12pt7b.h"

EInkDisplay_VisionMasterE290 display;
SensirionI2cSen66 sensor;

uint8_t padding = 0;
bool dataReady = false;
float massConcentrationPm1p0 = 0.0;
float massConcentrationPm2p5 = 0.0;
float massConcentrationPm4p0 = 0.0;
float massConcentrationPm10p0 = 0.0;
float humidity = 0.0;
float temperature = 0.0;
float vocIndex = 0.0;
float noxIndex = 0.0;
uint16_t co2 = 0;
float battV = 0;

void setup() {
  Serial.begin(115200);

  //Eink
  Platform::VExtOn();
  display.landscape();
  display.setFont(&FreeSans12pt7b);
  display.printCenter("Starting AQ SEN66");
  display.update();
  
  //Vbat
  analogReadResolution(12);
  pinMode(46, OUTPUT);
  digitalWrite(46, HIGH);
  pinMode(VBAT_PIN, INPUT);

  delay(50);

  //SEN66
  Wire.begin();
  sensor.begin(Wire, SEN66_I2C_ADDR_6B);
  delay(300);

  /* error = sensor.stopMeasurement();
  if (error != NO_ERROR) {
    display.printCenter("Failed to initialize SEN66");
  } */

  delay(50);
  error = sensor.startContinuousMeasurement();
  if (error != NO_ERROR) {
    display.printCenter("Failed to initialize SEN66");
  }

  int8_t serialNumber[32] = {0};
  error = sensor.getSerialNumber(serialNumber, 32);
  if (error != NO_ERROR) {
      display.printCenter("Failed to initialize SEN66");
      Serial.print("Error trying to execute getSerialNumber(): ");
      errorToString(error, errorMessage, sizeof errorMessage);
      Serial.println(errorMessage);
      return;
  }
  Serial.print("serialNumber: ");
  Serial.print((const char*)serialNumber);
  Serial.println();

  if (error == NO_ERROR) {
    display.clearMemory();
    display.printCenter("AQ Started");
    display.update();
  }
  delay(3000);
  display.setFont(&FreeSans12pt7b); //assure correct font
}

void goLightSleepFor(uint64_t seconds) {
  Platform::VExtOff();
  esp_sleep_enable_timer_wakeup(seconds * 1000000ULL);
  esp_light_sleep_start();
  Platform::VExtOn();
}

void drawRightAligned(int rightX, int y, const String &text)
{
    int16_t x1, y1;
    uint16_t w, h;

    display.getTextBounds(text, 0, y, &x1, &y1, &w, &h);
    display.setCursor(rightX - w, y);
    display.print(text);
}

void drawRow(int xLabel, int xValueRight, int y,
             const char *label,
             const String &value,
             const char *unit = "",
             bool unitBelow = false)
{
    display.setCursor(xLabel, y);
    display.print(label);

    drawRightAligned(xValueRight, y, value);

    if (*unit) {
        if (unitBelow) {
            display.setCursor(xValueRight - 43, y + 15); // adjust to taste
            display.print(unit);
        } else {
            display.print(" ");
            display.print(unit);
        }
    }
}

void GetValues() {
  error = sensor.getDataReady(padding, dataReady);
  if (error != NO_ERROR) {
    dataReady = false;
    return;
  }
  if (dataReady) {
    error = sensor.readMeasuredValues(
      massConcentrationPm1p0, massConcentrationPm2p5, massConcentrationPm4p0,
      massConcentrationPm10p0, humidity, temperature, vocIndex, noxIndex,
      co2);
    if (error != NO_ERROR) {
      dataReady = false;
      return;
    }
  }
  //Read battery voltage
  battV = analogRead(VBAT_PIN)* Resolution * battery_in * coefficient * 4.9;//battary/4096*3.3*coefficient
}

void DrawValues() { 
  display.clearMemory();
  drawRow(5,   125, 22, "Temp", String(temperature)/*, "C"*/);
  drawRow(5,   125, 55, "PM1",  String(massConcentrationPm1p0));
  drawRow(5,   125, 78, "PM2.5",String(massConcentrationPm2p5));
  drawRow(5,   125, 101, "PM4",  String(massConcentrationPm4p0));
  drawRow(5,   125,124, "PM10", String(massConcentrationPm10p0));
  
  drawRow(160,260,22, "rH",  String(humidity)/*, "%"*/);
  drawRow(160,260,55, "iVOC", String((int)round(vocIndex)));
  drawRow(160,260,78, "iNOx", String((int)round(noxIndex)));
  drawRow(160,260,101, "CO2", String(co2)/*, "ppm", true*/);
  drawRow(160,260,124, "Vbat", String(battV)/*, "ppm", true*/);
  
  display.update();
}

void PrintValues() {
  Serial.print("massConcentrationPm1p0:");
  Serial.print(massConcentrationPm1p0);
  Serial.print(",");
  Serial.print("massConcentrationPm2p5:");
  Serial.print(massConcentrationPm2p5);
  Serial.print(",");
  /*Serial.print("massConcentrationPm4p0:"); // Arduino serial plotter supports only 8 channels
  Serial.print(massConcentrationPm4p0);
  Serial.print(",");*/
  Serial.print("massConcentrationPm10p0:");
  Serial.print(massConcentrationPm10p0);
  Serial.print(",");
  Serial.print("humidity:");
  Serial.print(humidity);
  Serial.print(",");
  Serial.print("temperature:");
  Serial.print(temperature);
  Serial.print(",");
  Serial.print("vocIndex:");
  Serial.print(vocIndex);
  Serial.print(",");
  Serial.print("noxIndex:");
  Serial.print(noxIndex);
  Serial.print(",");
  Serial.print("co2:");
  Serial.println(co2);
}

void loop() {
  GetValues();
  if (dataReady) {
    DrawValues();
  } else {
    display.clearMemory();
    display.printCenter("No data");
    display.update();
  }
  PrintValues();
  delay(1000);
  goLightSleepFor(28); // sleep ~1 minute
}

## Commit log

2026-03-21 In da benginging
    [BOM.csv, HeltecT114 - Simplified dimensional drawing.stl, MeshAQ-CAD.FCStd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]
2026-03-25 First draft of the case
    [BOM.csv, MeshAQ-CAD.FCStd, bender.FCStd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]
2026-03-26 finished it
    [BOM.csv, MeshAQ-3DPrintFile.3mf, MeshAQ-CAD.FCStd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]
2026-03-27 updated links and prices because on Farnel it was without VAT and links
    [BOM.csv]
2026-06-30 Small pivot
    [BOM.csv, MeshAQ-CAD.FCStd]
2026-07-01 managed to get the ESP counting.
    [BOM.csv]
2026-07-01 Prototype: created first halve for inegrating the SEN.
2026-07-02 It works! with the SEN66 sensor
2026-07-02 added battery info
2026-07-02 Finishing touches.
    [MeshAQ-3DPrintFile.3mf, MeshAQ-CAD.FCStd, MeshAQ-CAD.step]
2026-07-12 vibecoded MVP prototype for t114
2026-07-12 Revert "Tried vibecoding the GPS but wo luck."
    This reverts commit 6e1e312a15088a26763620e685f89bcf43b03a81.
    [t114_prototype.ino]
2026-08-16 updated the repo and prepaired to migrate to stardance
    [MeshAQ-3DPrintFile.3mf, MeshAQ-CAD.FCStd, MeshAQ-CAD.step]
